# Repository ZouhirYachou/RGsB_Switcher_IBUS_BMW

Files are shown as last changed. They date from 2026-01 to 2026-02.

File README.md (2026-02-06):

# RGsB Switcher for IBUS BMW E series

This PCB is meant to be used with this RPI Hat https://github.com/ZouhirYachou/RPI5_RGsB_HAT<br/>

<p align="center">
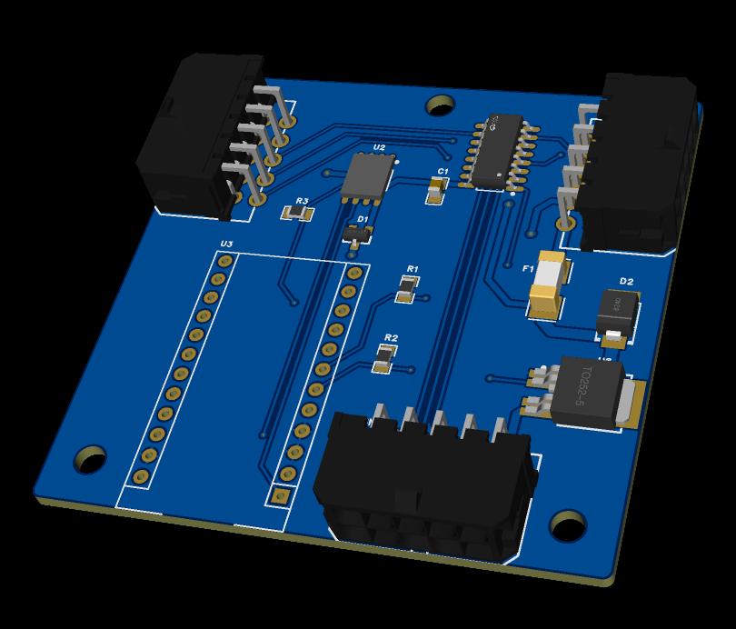
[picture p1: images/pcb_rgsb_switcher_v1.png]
  
</p>

## Purpose / Features
- Reads IBUS messages and power on the Arduino when IBUS activity is dectected
- Only sends power to the RPI when IGN POS2 is dectected (Same as original Radio/NAV)
- When RPI input is selected, with the "PHONE" button, some radio buttons are used to control the Carplay / Android Auto on the RPI
- Radio buttons that changes the display of the original NAV, sends you back to default display (Analog RGB RPI output is set to OFF)
- Only reads IBUS, does not sends messages
- Not modification required to the original system as it is installed between the NAV and the CID (NAV Display)

## Repository contents
- `hardware` Schematic, Gerber, BOM, Pick and place for PCB fabrication
- `STLs` 3d files to print your own case for this hat
- `Arduino` Arduino code to flash into the Arduino Pro Micro

## Getting started
1. Flash the Arduino 
2. Install the assembled PCB with the Arduino into the car
3. Connect a USB cable between the Arduino and the RPI to send the keyboard strokes to the RPI
3. Press the "PHONE" button after car is strated or IGN in position 2
4. Carplay / Android Auto should show if you installed this solution https://github.com/f-io/LIVI

## 3D Printed Case
Provided STLs should be printed either with ABS or ASA<br/>
It requires the following fasteners:
| Fasteners | Quantity |
| --- |:---:|
| M3*20mm | 3 |

<p align="center">
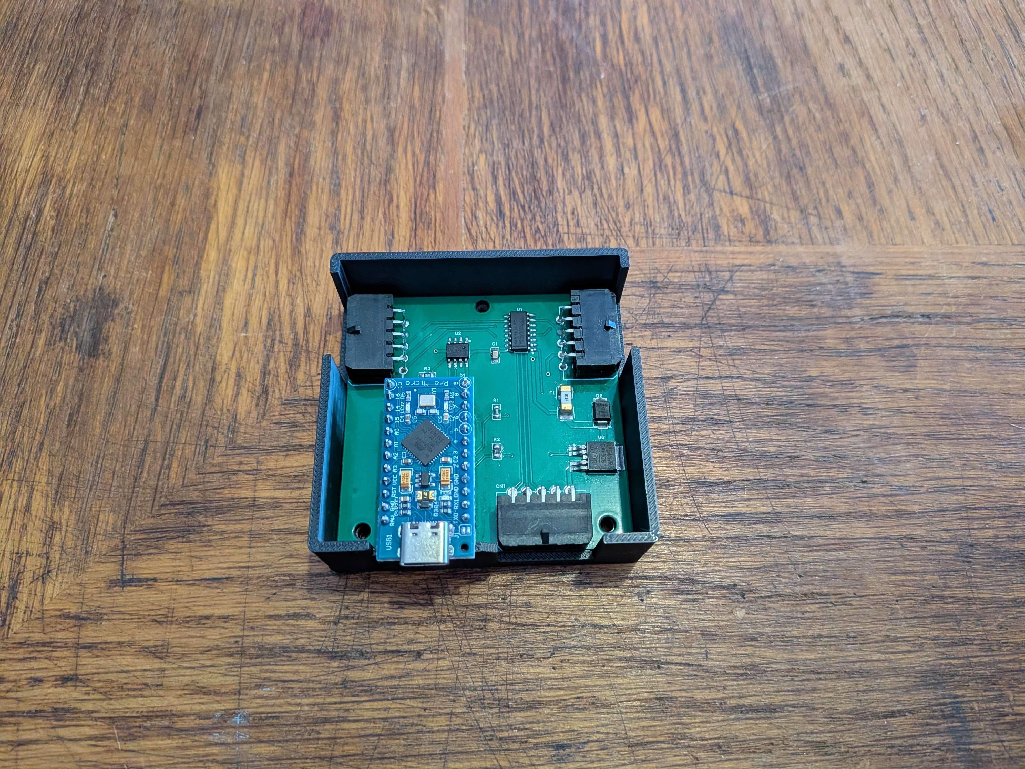
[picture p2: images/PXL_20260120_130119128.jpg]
  
</p>

<p align="center">
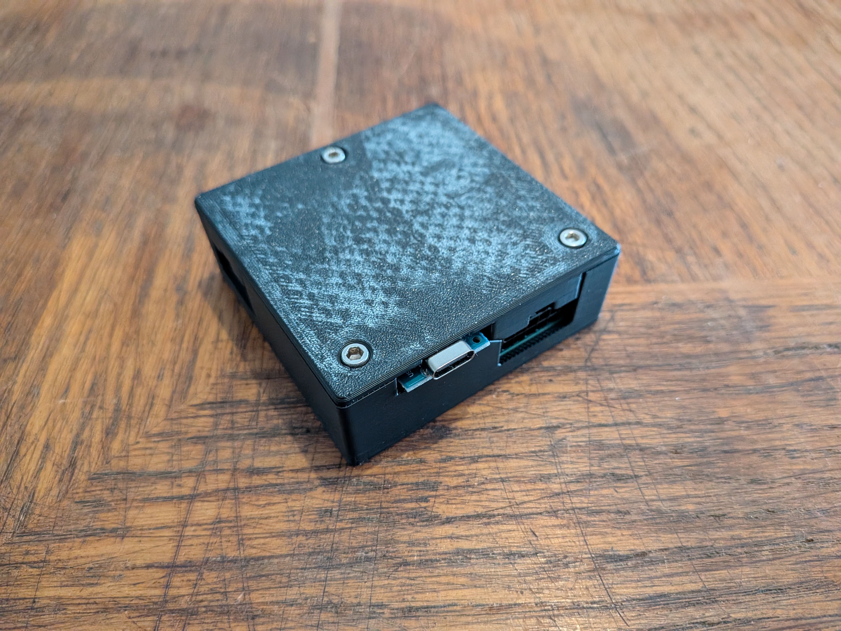
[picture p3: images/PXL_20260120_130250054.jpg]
  
</p>

## Wiring diagram
This explains how this PCB is connected to the car and the RPI<br/>

<p align="center">
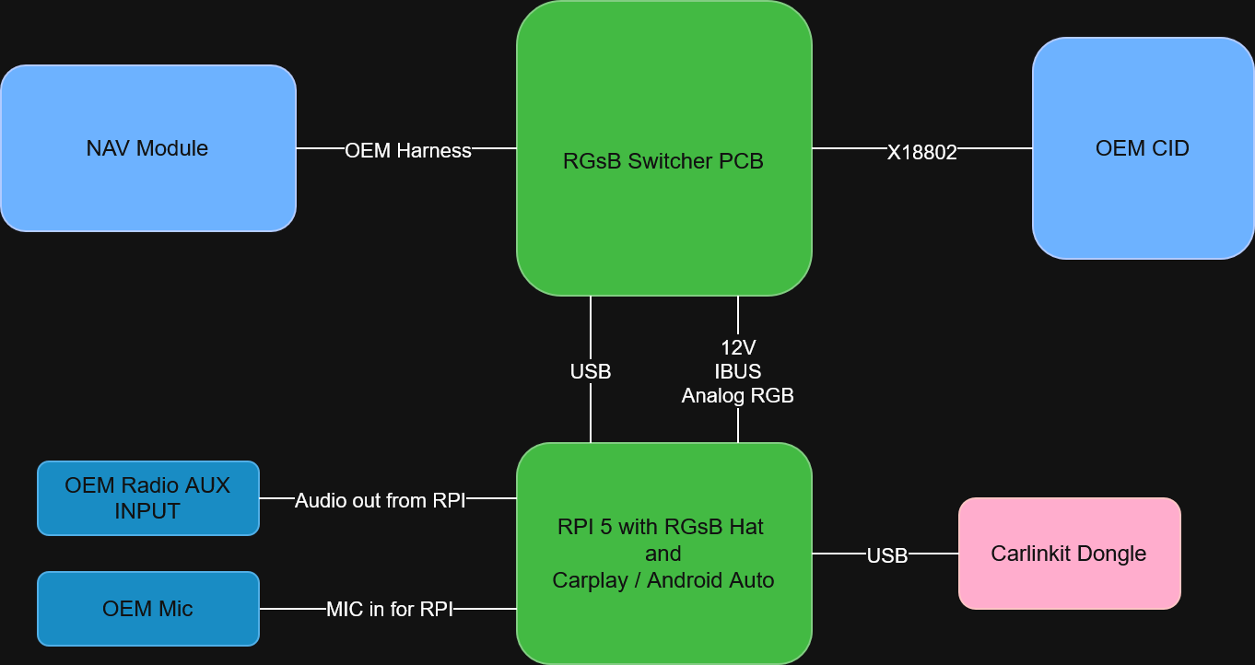
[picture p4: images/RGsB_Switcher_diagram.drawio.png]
  
</p>

## Safety / Warnings
- Tested inside the car for 2 weeks, nothing blew up, yet, but the design can be improved to be more resilient for car electric systems.

## Todo list
- Improve the design with integrated MCU
- Single board with RPI CM5 

## Images

Once installed
<p align="center">
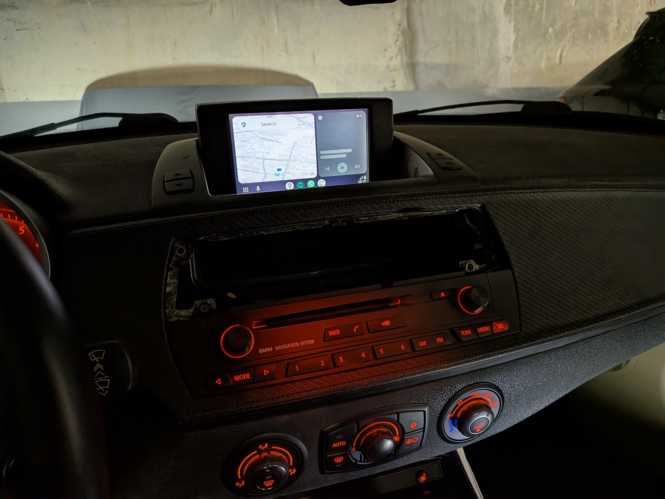
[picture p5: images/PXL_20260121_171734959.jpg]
  
</p>

## Contributing
- Any improvements on the design are welcome.

## References
- https://www.e46fanatics.com/threads/bmw-on-board-monitor-without-navigation-unit.1303552
- https://github.com/f-io/LIVI
- https://bmwteka.com/wds/en/e85/e82460cf
- https://bmwteka.com/wds/en/e85/1b7f9876

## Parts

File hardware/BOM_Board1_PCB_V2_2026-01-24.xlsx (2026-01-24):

No. | Quantity | Comment | Designator | Footprint | Value | Manufacturer Part | Manufacturer | Supplier Part | Supplier
1 | 1 | 100nF | C1 | C0805 | 100nF | CL21B104KBCNNNC | SAMSUNG(三星) | C1711 | LCSC
2 | 1 | MOLEX RGsB RPI | CN1 | CONN-TH_43045-1000 |  | MOLEX RGsB RPI | MOLEX | C122421 | LCSC
3 | 1 | MOLEX CAR IN | CN2 | CONN-TH_43045-1000 |  | MOLEX CAR IN | MOLEX | C122421 | LCSC
4 | 1 | MOLEX CAR OUT | CN3 | CONN-TH_43045-1000 |  | MOLEX CAR OUT | MOLEX | C122421 | LCSC
5 | 1 | BAT54,215 | D1 | SOT-23_L2.9-W1.3-P1.90-LS2.4-BR |  | BAT54,215 | Nexperia(安世) | C85084 | LCSC
6 | 1 | SMBJ18A | D2 | SMB_L4.3-W3.6-LS5.3-RD |  | SMBJ18A | Littelfuse(美国力特) | C151256 | LCSC
7 | 1 | 0451003.MRL | F1 | FUSE-SMD_L6.1-W2.7 |  | 0451003.MRL | Littelfuse(美国力特) | C13982 | LCSC
8 | 3 | 10kΩ | R1,R2,R3 | R0805 | 10kΩ | RC0805FR-0710KL | YAGEO(国巨) | C84376 | LCSC
9 | 1 | TS5V330CDR | U1 | SOIC-16_L9.9-W3.9-P1.27-LS6.0-BL |  | TS5V330CDR | TI(德州仪器) | C2652482 | LCSC
10 | 1 | MCP2025-500E/SN | U2 | SOIC-8_L4.9-W3.9-P1.27-LS6.0-BL |  | MCP2025-500E/SN | MICROCHIP(美国微芯) | C635947 | LCSC
11 | 1 | Arduino_Pro_Micro | U3 | Sparkfun_Pro_Micro
12 | 1 | BTS452R | U6 | TO-252-5_L6.5-W6.2-P1.14-LS10.0-TL |  | BTS452R | Infineon(英飞凌) | C126924 | LCSC

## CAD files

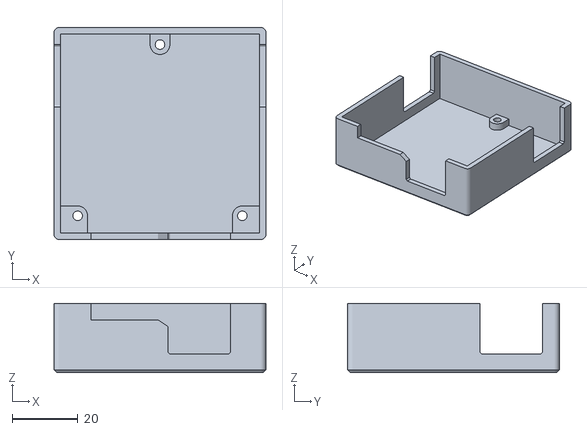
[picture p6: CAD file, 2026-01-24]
STLs/Bottom_Case_RGsB_Switcher.stl
64.4 x 64.4 x 21.0

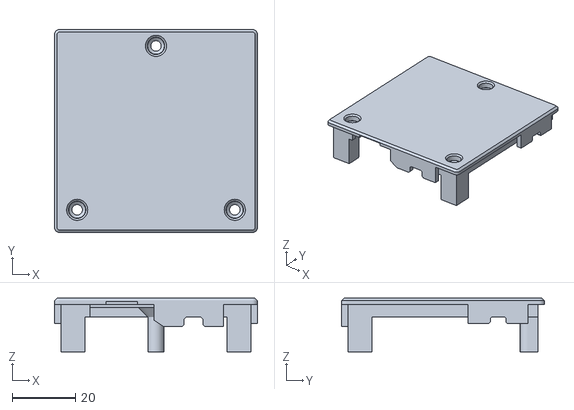
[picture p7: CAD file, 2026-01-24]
STLs/Top_Case_RGsB_Switcher.stl
64.4 x 64.4 x 17.0

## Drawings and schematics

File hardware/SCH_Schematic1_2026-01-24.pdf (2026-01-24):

# S2C 10 S1C 11 DD 12 S2D 13 S1D 14 EN# 15 VCC 16

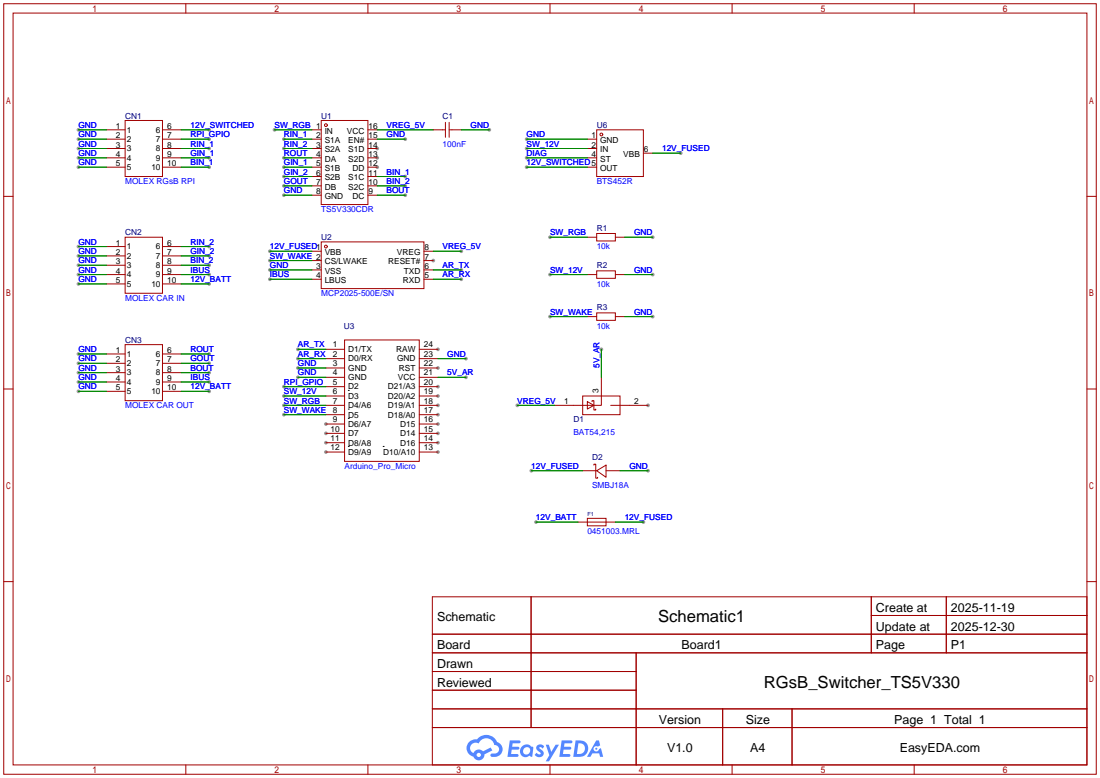
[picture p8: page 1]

D21/A3 20 VCC 21 RST 22 GND 23 RAW 24

Schematic | Schematic1 | Create at | 2025-11-19

Update at | 2025-12-30

Board | Board1 | Page | P1
Drawn | | RGsB_Switcher_TS5V330
Reviewed

Version | Size | Page 1 Total 1
V1.0 | A4 | EasyEDA.com

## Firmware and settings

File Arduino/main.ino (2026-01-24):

#include <Arduino.h>
#include <IbusTrx.h>
#include <Keyboard.h>
#include "IbusMessages.h"

// RPI Control GPIO
// Currently not implemented as the GPIO for RPI is 3.3V
const uint8_t RPI_GPIO_PIN = 2;

// Switch 12V output to RPI
const uint8_t SW_12V_PIN = 3;

// Switch RGB input
const uint8_t SW_RGB_PIN = 4;

// Switch ON/OFF MCP2025
const uint8_t SW_WAKE_PIN = 5;

IbusTrx ibusTrx;

// Timeout when no IBUS activity
static unsigned long lastIbusActivityMs = 0;
static bool slept = false;

// Timeout set to 10 seconds of inactivity
const unsigned long IBUS_INACTIVITY_TIMEOUT_MS = 10000;

// SELECT button toggles between Arrow UP and Arrow DOWN
static bool selectSendsUp = true;

// Only send USB keystrokes when SW_RGB_PIN is LOW (RPI Analog RGB enabled)
static inline bool rpiAnalogRgbEnabled() {
  return digitalRead(SW_RGB_PIN) == LOW;
}

static void sendKey(uint8_t key, uint8_t times = 1) {
  if (!rpiAnalogRgbEnabled()) return;
  for (uint8_t i = 0; i < times; i++) {
    Keyboard.write(key);
  }
}

static void switchRpiGpio(uint8_t pinState) {
  digitalWrite(RPI_GPIO_PIN, pinState);
}

static void switchPowerRpi(uint8_t pinState) {
  digitalWrite(SW_12V_PIN, pinState);
}

static void switchAnalogRgbInput(uint8_t pinState) {
  digitalWrite(SW_RGB_PIN, pinState);
}

static void switchLinIC(uint8_t pinState) {
  digitalWrite(SW_WAKE_PIN, pinState);
}

static void SleepMode() {
  // Stop UART so TXD is LOW
  Serial1.end();

  // Force TXD low (pin 1 on Arduino Pro Micro)
  pinMode(1, OUTPUT);
  digitalWrite(1, LOW);

  delay(50); // Ensure TXD is stable low

  // Sleep mode on MCP2025 with WAKE pin LOW
  switchLinIC(LOW);

  delay(50);
}

void setup() {
  // RPI GPIO set to LOW always to prevent 5V into GPIO of RPI
  pinMode(RPI_GPIO_PIN, OUTPUT);
  switchRpiGpio(LOW);

  // 12V to RPI is OFF wehn ardunio setup (wait for IGN to start)
  pinMode(SW_12V_PIN, OUTPUT);
  switchPowerRpi(LOW);

  // Analog RGB input from NAV module on startup
  pinMode(SW_RGB_PIN, OUTPUT);
  switchAnalogRgbInput(HIGH);

  // Make sure the MCP2025 is in normal mode
  pinMode(SW_WAKE_PIN, OUTPUT);
  switchLinIC(HIGH);

  delay(50);

  // IBUS is 9600 8E1 on BMW
  Serial1.begin(9600, SERIAL_8E1);
  ibusTrx.begin(Serial1);
  lastIbusActivityMs = millis();
  slept = false;

  // USB HID init    
  Keyboard.begin();
  delay(500);

}

void loop() {
  // Read complete IBUS messages via IbusTrx
  if (ibusTrx.available()) {
    IbusMessage msg = ibusTrx.readMessage();

    lastIbusActivityMs = millis();

    // IGN handling
    if (ibusIsIgnPos2(msg)) {
      switchPowerRpi(HIGH);  // Enable 12V only when IGN is POS2
    }
    if (ibusIsIgnOff(msg)) {
      switchPowerRpi(LOW); // Turn of 12v to RPI when IGN is OFF
    }

    if (ibusIsTelephonePressed(msg)) {
      switchAnalogRgbInput(digitalRead(SW_RGB_PIN) == HIGH ? LOW : HIGH);
    }

    // Force back to NAV RGB input (disable RPI analog RGB) when the buttons below are pressed
    if (ibusIsAmPressed(msg) || ibusIsFmPressed(msg) ||
              ibusIsTonePressed(msg) || ibusIsMenuPressed(msg) ||
              ibusIsModePressed(msg) || ibusIsInfoPressed(msg) ||
              ibusIsRadioBmPressed(msg)) {
      switchAnalogRgbInput(HIGH);
    }

    // Keyboard strokes for each radio buttons presses
    if (ibusIsPreset1Pressed(msg)) {
      sendKey('h');
    } else if (ibusIsPreset2Pressed(msg)) {
      sendKey(KEY_BACKSPACE);
    } else if (ibusIsPreset3Pressed(msg)) {
      sendKey('p');
    } else if (ibusIsPreset4Pressed(msg)) {
      sendKey('s');
    } else if (ibusIsPreset5Pressed(msg)) {
      sendKey(KEY_UP_ARROW);
    } else if (ibusIsPreset6Pressed(msg)) {
      sendKey(KEY_DOWN_ARROW);

    } else if (ibusIsMflSendEndPressed(msg)) {
      sendKey('v');
    } else if (ibusIsMflModeTogglePressed(msg)) {
      sendKey('a');
    }

    if (ibusIsSearchUpPressed(msg)) {
      sendKey('n');
    } else if (ibusIsSearchDownPressed(msg)) {
      sendKey('b');
    } else if (ibusIsSearchLeftPressed(msg)) {
      sendKey('b');
    } else if (ibusIsSearchRightPressed(msg)) {
      sendKey('n');
    } else if (ibusIsSelectPressed(msg)) {
      sendKey(selectSendsUp ? KEY_UP_ARROW : KEY_DOWN_ARROW);
      selectSendsUp = !selectSendsUp;
    } else if (ibusIsBmKnobPressed(msg)) {
      sendKey(KEY_RETURN);
    } else if (ibusIsBmKnobRight(msg, 1)) {
      sendKey(KEY_RIGHT_ARROW, 1);
    } else if (ibusIsBmKnobRight(msg, 2)) {
      sendKey(KEY_RIGHT_ARROW, 2);
    } else if (ibusIsBmKnobRight(msg, 3)) {
      sendKey(KEY_RIGHT_ARROW, 3);
    } else if (ibusIsBmKnobRight(msg, 4)) {
      sendKey(KEY_RIGHT_ARROW, 4);
    } else if (ibusIsBmKnobLeft(msg, 1)) {
      sendKey(KEY_LEFT_ARROW, 1);
    } else if (ibusIsBmKnobLeft(msg, 2)) {
      sendKey(KEY_LEFT_ARROW, 2);
    } else if (ibusIsBmKnobLeft(msg, 3)) {
      sendKey(KEY_LEFT_ARROW, 3);
    } else if (ibusIsBmKnobLeft(msg, 4)) {
      sendKey(KEY_LEFT_ARROW, 4);
    }
  }
  // Sleep mode for the MCP2025 when no IBUS activity detected for 10 seconds (Car is off and closed)
  if (!slept && (millis() - lastIbusActivityMs > IBUS_INACTIVITY_TIMEOUT_MS)) {
    SleepMode();
    slept = true;   // prevent calling SleepMode() repeatedly
  }

}
